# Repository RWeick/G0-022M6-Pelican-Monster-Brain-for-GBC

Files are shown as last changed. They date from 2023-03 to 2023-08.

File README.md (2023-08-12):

# G0-022M6-Pelican-Monster-Brain-for-GBC
The schematics, PCB, and flash dumps of three versions of the GBC Pelican Monster Brain.

Version 1.1 is for Pokemon Red and Blue, and comes in a case with a blue BrainBoy sticker/logo.
Version 2.0 is for Pokemon Gold and Silver, and comes in a case with a gold BrainBoy sticker/logo.
Version 3.6 is for every Gameboy Pokemon edition, and comes in a case with a purple Monster Brain sticker/logo.

All components labeled "Unknown" in the schematic were not present on the commercial PCB. This PCB is used for both the Monster Brain and the Codebreaker, and the missing components are present when this board is used in a Codebreaker.

The CPLD is the same between all devices.

The Colorizer button PCB wires solder to the inner two pads of the 4 at the rear top edge of the PCB.

Jumper configuration for normal operation: 

- J1: Pads 2 and 3 are shorted.
- J2: Open.
- J3: Shorted.
- J4: Shorted.

The CPLD functions I've been able to deduce are as follows:

A read must be performed at address 0x100 in order to enable address banking in the CPLD.

The write address to change banks is 0xA000.

The full rom is available from 0x2000 to 0x3FFF by switching either 32 or 64 banks depending on the device. The blue label Brainboy has 64 banks, and the rest of the devices use 32 banks due to smaller eeproms. The maximum known EEPROM size included with an off the shelf device is 512 KB.

PCB Thickness: 0.8 mm

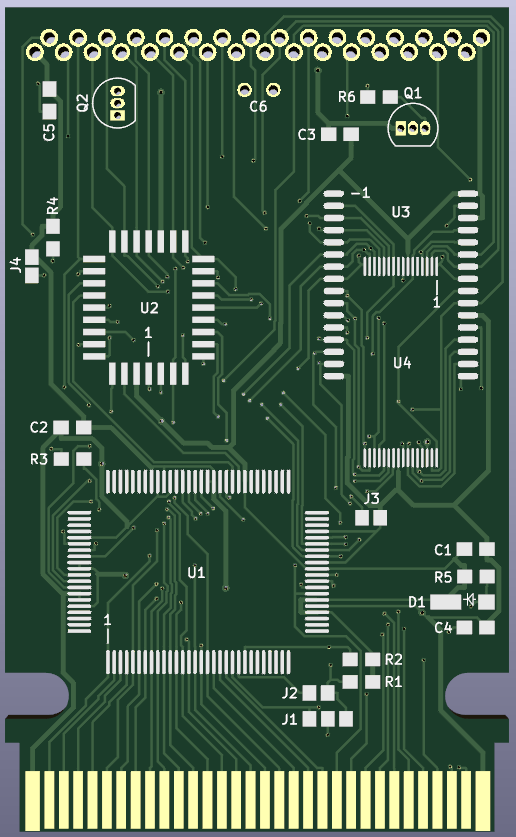
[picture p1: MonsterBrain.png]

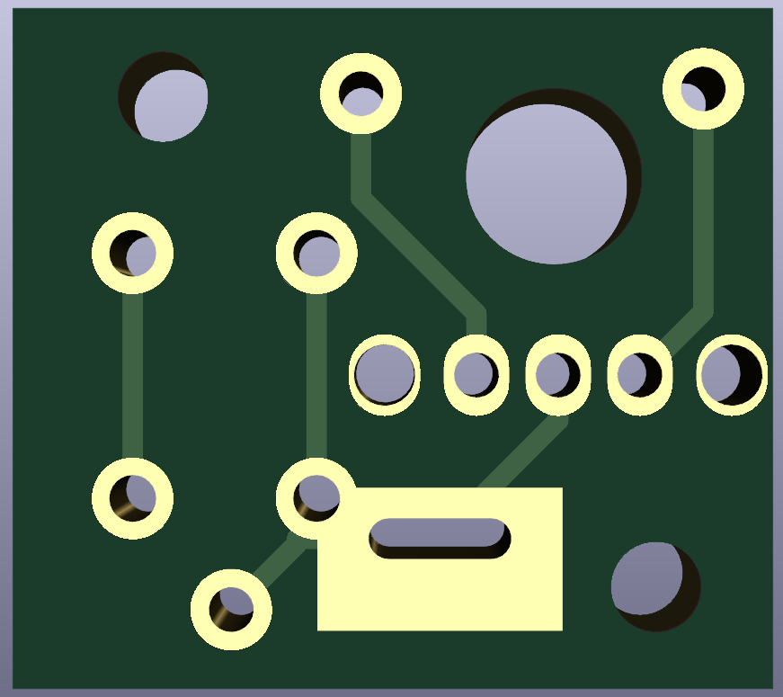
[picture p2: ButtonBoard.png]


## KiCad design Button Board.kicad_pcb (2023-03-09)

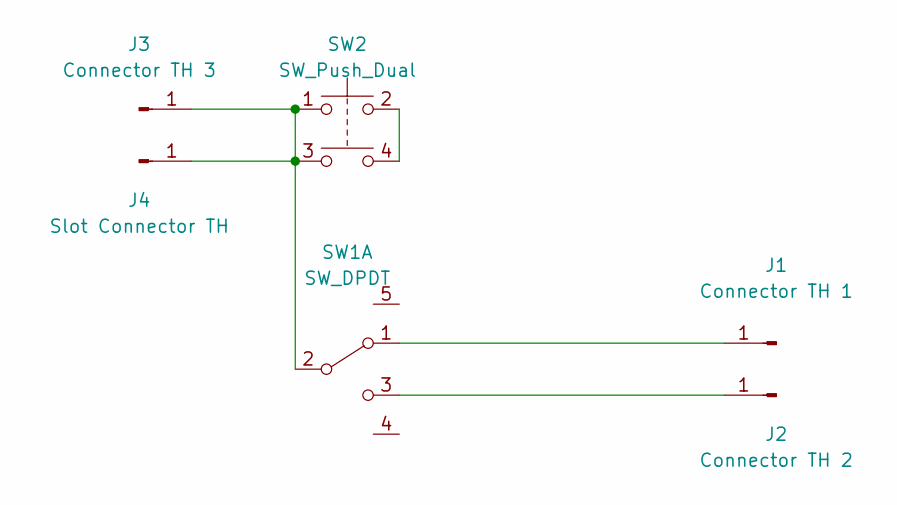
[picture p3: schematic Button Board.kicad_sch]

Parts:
J1: Connector TH 1; Connector Hole
J2: Connector TH 2; Connector Hole
J3: Connector TH 3; Connector Hole
J4: Slot Connector TH; Square Slot
SW1: SW_DPDT; Sliding Switch
SW2: SW_Push_Dual; Push Button

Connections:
unnamed: J1.1, SW1.1 (A)
unnamed: J2.1, SW1.3 (C)
unnamed: J3.1, J4.1, SW1.2 (B), SW2.1, SW2.3
unnamed: SW2.2, SW2.4

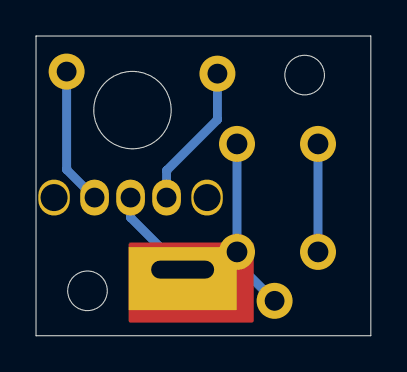
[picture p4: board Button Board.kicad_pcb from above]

Board: 2 copper layers, 18.6 x 16.6 mm, 9 parts (0 on the bottom side), 4 nets.

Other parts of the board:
H1, H3: MountingHole_2.2mm_M2
H2: MountingHole_4.3mm_M4

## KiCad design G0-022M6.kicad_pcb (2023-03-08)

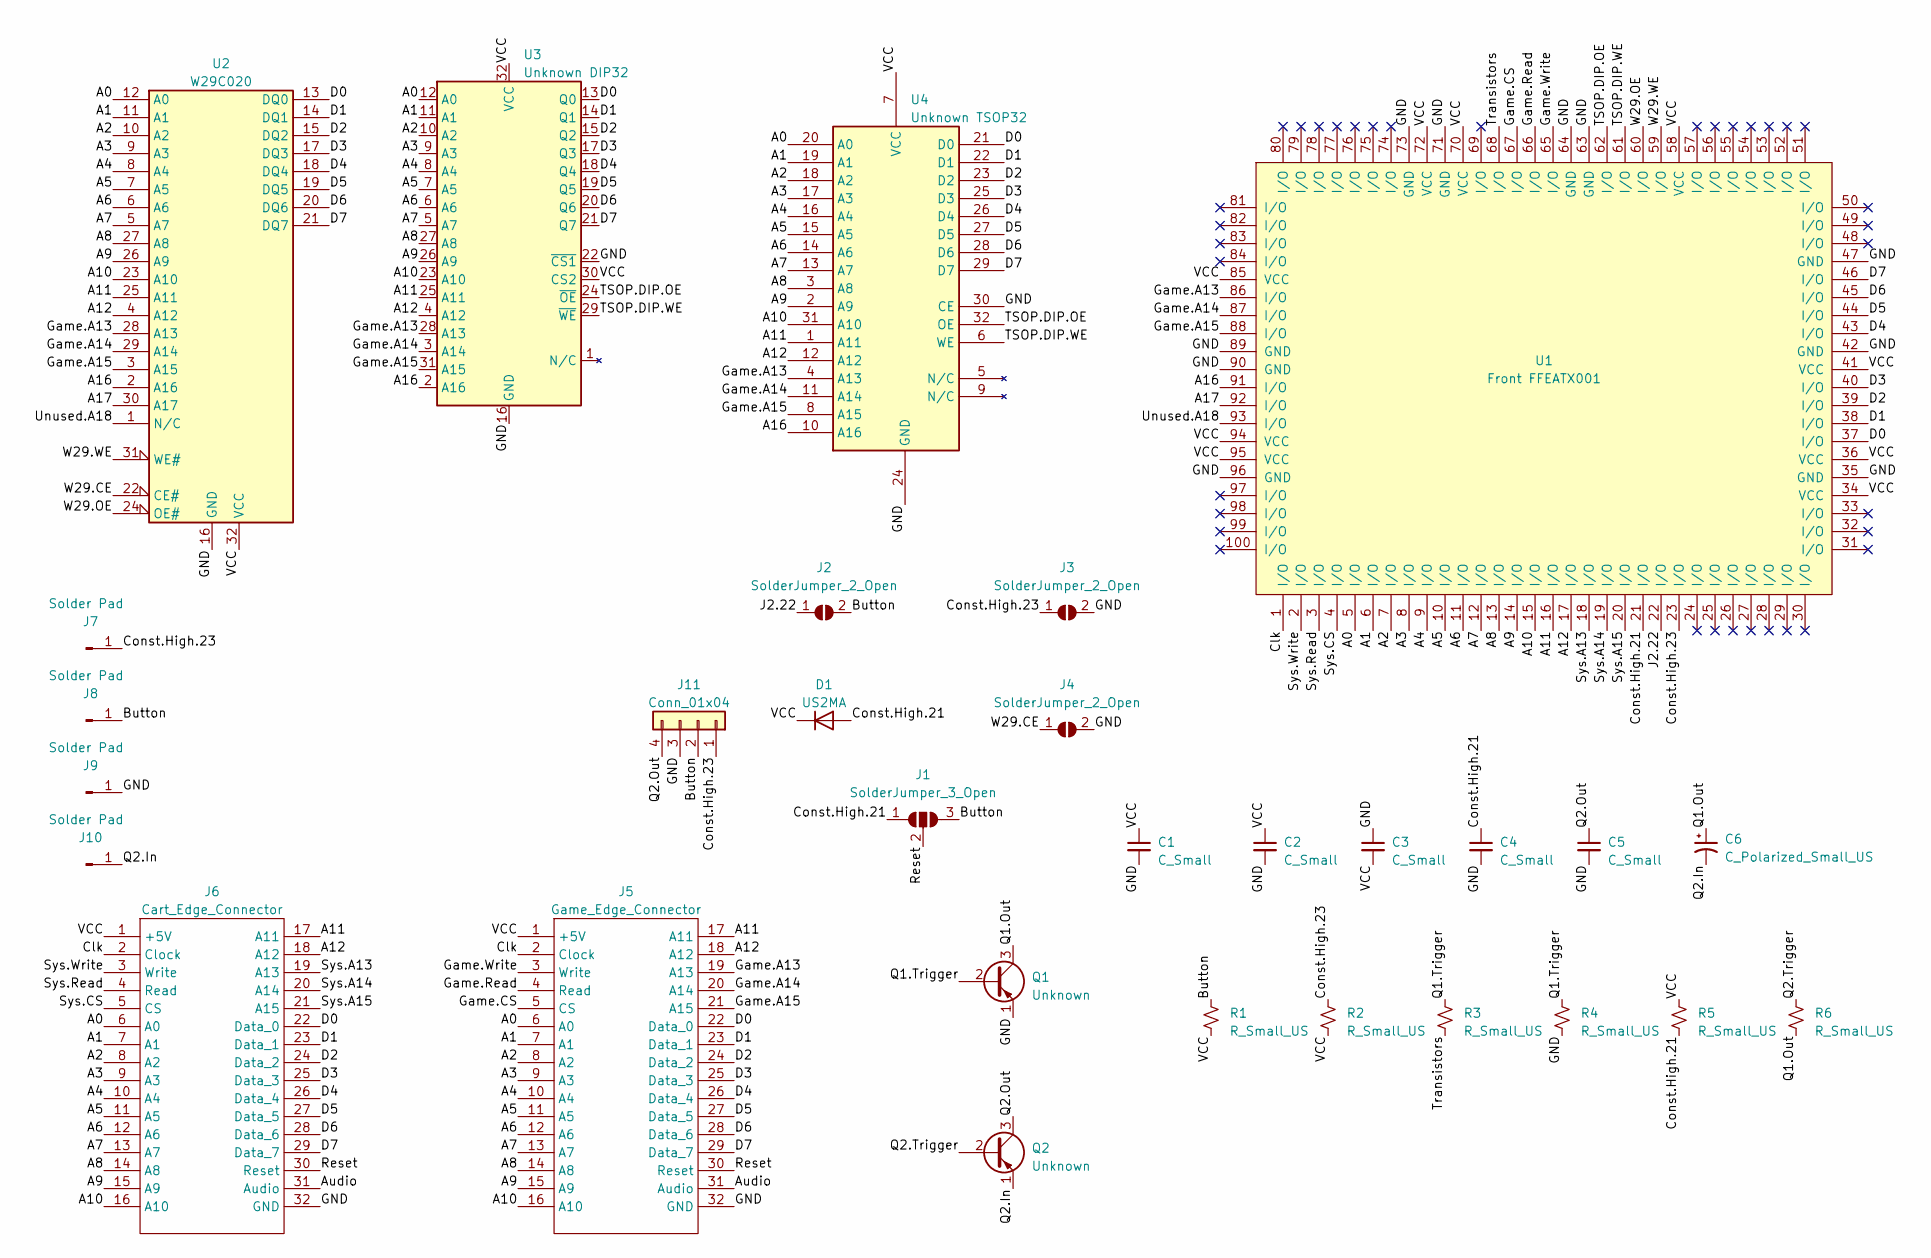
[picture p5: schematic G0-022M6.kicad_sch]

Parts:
C1, C2, C3, C4, C5: C_Small; SMD Cap
C6: C_Polarized_Small_US; TH Cap
D1: US2MA; Diode
J1: SolderJumper_3_Open; 3 Pad Jumper
J2, J3, J4: SolderJumper_2_Open; 2 Pad Jumper
J5: Game_Edge_Connector; Cartridge Slot, GBC
J6: Cart_Edge_Connector; ACTUAL GAMEBOY EDGE CONNECTOR
J7, J8, J9, J10: Solder Pad; Rear Circle Pad
J11: Conn_01x04; Rear Edge
Q1, Q2: Unknown; TO-92_Inline
R1, R2, R3, R4, R5, R6: R_Small_US; SMD Res
U1: Front FFEATX001; FFEATX001
U2: W29C020
U3: Unknown DIP32; Unknown Dip
U4: Unknown TSOP32; Unknown TSOP

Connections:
/A0: J5.6 (A0), J6.6 (A0), U1.5 (I/O), U2.12 (A0), U3.12 (A0), U4.20 (A0)
/A1: J5.7 (A1), J6.7 (A1), U1.6 (I/O), U2.11 (A1), U3.11 (A1), U4.19 (A1)
/A2: J5.8 (A2), J6.8 (A2), U1.7 (I/O), U2.10 (A2), U3.10 (A2), U4.18 (A2)
/A3: J5.9 (A3), J6.9 (A3), U1.8 (I/O), U2.9 (A3), U3.9 (A3), U4.17 (A3)
/A4: J5.10 (A4), J6.10 (A4), U1.9 (I/O), U2.8 (A4), U3.8 (A4), U4.16 (A4)
/A5: J5.11 (A5), J6.11 (A5), U1.10 (I/O), U2.7 (A5), U3.7 (A5), U4.15 (A5)
/A6: J5.12 (A6), J6.12 (A6), U1.11 (I/O), U2.6 (A6), U3.6 (A6), U4.14 (A6)
/A7: J5.13 (A7), J6.13 (A7), U1.12 (I/O), U2.5 (A7), U3.5 (A7), U4.13 (A7)
/A8: J5.14 (A8), J6.14 (A8), U1.13 (I/O), U2.27 (A8), U3.27 (A8), U4.3 (A8)
/A9: J5.15 (A9), J6.15 (A9), U1.14 (I/O), U2.26 (A9), U3.26 (A9), U4.2 (A9)
/A10: J5.16 (A10), J6.16 (A10), U1.15 (I/O), U2.23 (A10), U3.23 (A10), U4.31 (A10)
/A11: J5.17 (A11), J6.17 (A11), U1.16 (I/O), U2.25 (A11), U3.25 (A11), U4.1 (A11)
/A12: J5.18 (A12), J6.18 (A12), U1.17 (I/O), U2.4 (A12), U3.4 (A12), U4.12 (A12)
/A16: U1.91 (I/O), U2.2 (A16), U3.2 (A16), U4.10 (A16)
/A17: U1.92 (I/O), U2.30 (A17)
/Audio: J5.31 (Audio), J6.31 (Audio)
/Button: J1.3 (B), J2.2 (B), J8.1, J11.2, R1.1
/Clk: J5.2 (Clock), J6.2 (Clock), U1.1 (I/O)
/Const.High.21: C4.1, D1.2 (A), J1.1 (A), R5.2, U1.21 (I/O)
/Const.High.23: J3.1 (A), J7.1, J11.1, R2.1, U1.23 (I/O)
/D0: J5.22 (Data_0), J6.22 (Data_0), U1.37 (I/O), U2.13 (DQ0), U3.13 (Q0), U4.21 (D0)
/D1: J5.23 (Data_1), J6.23 (Data_1), U1.38 (I/O), U2.14 (DQ1), U3.14 (Q1), U4.22 (D1)
/D2: J5.24 (Data_2), J6.24 (Data_2), U1.39 (I/O), U2.15 (DQ2), U3.15 (Q2), U4.23 (D2)
/D3: J5.25 (Data_3), J6.25 (Data_3), U1.40 (I/O), U2.17 (DQ3), U3.17 (Q3), U4.25 (D3)
/D4: J5.26 (Data_4), J6.26 (Data_4), U1.43 (I/O), U2.18 (DQ4), U3.18 (Q4), U4.26 (D4)
/D5: J5.27 (Data_5), J6.27 (Data_5), U1.44 (I/O), U2.19 (DQ5), U3.19 (Q5), U4.27 (D5)
/D6: J5.28 (Data_6), J6.28 (Data_6), U1.45 (I/O), U2.20 (DQ6), U3.20 (Q6), U4.28 (D6)
/D7: J5.29 (Data_7), J6.29 (Data_7), U1.46 (I/O), U2.21 (DQ7), U3.21 (Q7), U4.29 (D7)
/GND: C1.2, C2.2, C3.1, C4.2, C5.2, J3.2 (B), J4.2 (B), J5.32 (GND), J6.32 (GND), J9.1, J11.3, Q1.1 (E), R4.2, U1.35 (GND), U1.42 (GND), U1.47 (GND), U1.63 (GND), U1.64 (GND), U1.71 (GND), U1.73 (GND), U1.89 (GND), U1.90 (GND), U1.96 (GND), U2.16 (GND), U3.16 (GND), U3.22 (~CS1), U4.24 (GND), U4.30 (CE)
/Game.A13: J5.19 (A13), U1.86 (I/O), U2.28 (A13), U3.28 (A13), U4.4 (A13)
/Game.A14: J5.20 (A14), U1.87 (I/O), U2.29 (A14), U3.3 (A14), U4.11 (A14)
/Game.A15: J5.21 (A15), U1.88 (I/O), U2.3 (A15), U3.31 (A15), U4.8 (A15)
/Game.CS: J5.5 (CS), U1.67 (I/O)
/Game.Read: J5.4 (Read), U1.66 (I/O)
/Game.Write: J5.3 (Write), U1.65 (I/O)
/J2.22: J2.1 (A), U1.22 (I/O)
/Q1.Out: C6.1, Q1.3 (C), R6.2
/Q1.Trigger: Q1.2 (B), R3.1, R4.1
/Q2.In: C6.2, J10.1, Q2.1 (E)
/Q2.Out: C5.1, J11.4, Q2.3 (C)
/Q2.Trigger: Q2.2 (B), R6.1
/Reset: J1.2 (C), J5.30 (Reset), J6.30 (Reset)
/Sys.A13: J6.19 (A13), U1.18 (I/O)
/Sys.A14: J6.20 (A14), U1.19 (I/O)
/Sys.A15: J6.21 (A15), U1.20 (I/O)
/Sys.CS: J6.5 (CS), U1.4 (I/O)
/Sys.Read: J6.4 (Read), U1.3 (I/O)
/Sys.Write: J6.3 (Write), U1.2 (I/O)
/TSOP.DIP.OE: U1.62 (I/O), U3.24 (~OE), U4.32 (OE)
/TSOP.DIP.WE: U1.61 (I/O), U3.29 (~WE), U4.6 (WE)
/Transistors: R3.2, U1.68 (I/O)
/Unused.A18: U1.93 (I/O), U2.1 (N/C)
/VCC: C1.1, C2.1, C3.2, D1.1 (K), J5.1 (+5V), J6.1 (+5V), R1.2, R2.2, R5.1, U1.34 (VCC), U1.36 (VCC), U1.41 (VCC), U1.58 (VCC), U1.70 (VCC), U1.72 (VCC), U1.85 (VCC), U1.94 (VCC), U1.95 (VCC), U2.32 (VCC), U3.30 (CS2), U3.32 (VCC), U4.7 (VCC)
/W29.CE: J4.1 (A), U2.22 (CE#)
/W29.OE: U1.60 (I/O), U2.24 (OE#)
/W29.WE: U1.59 (I/O), U2.31 (WE#)

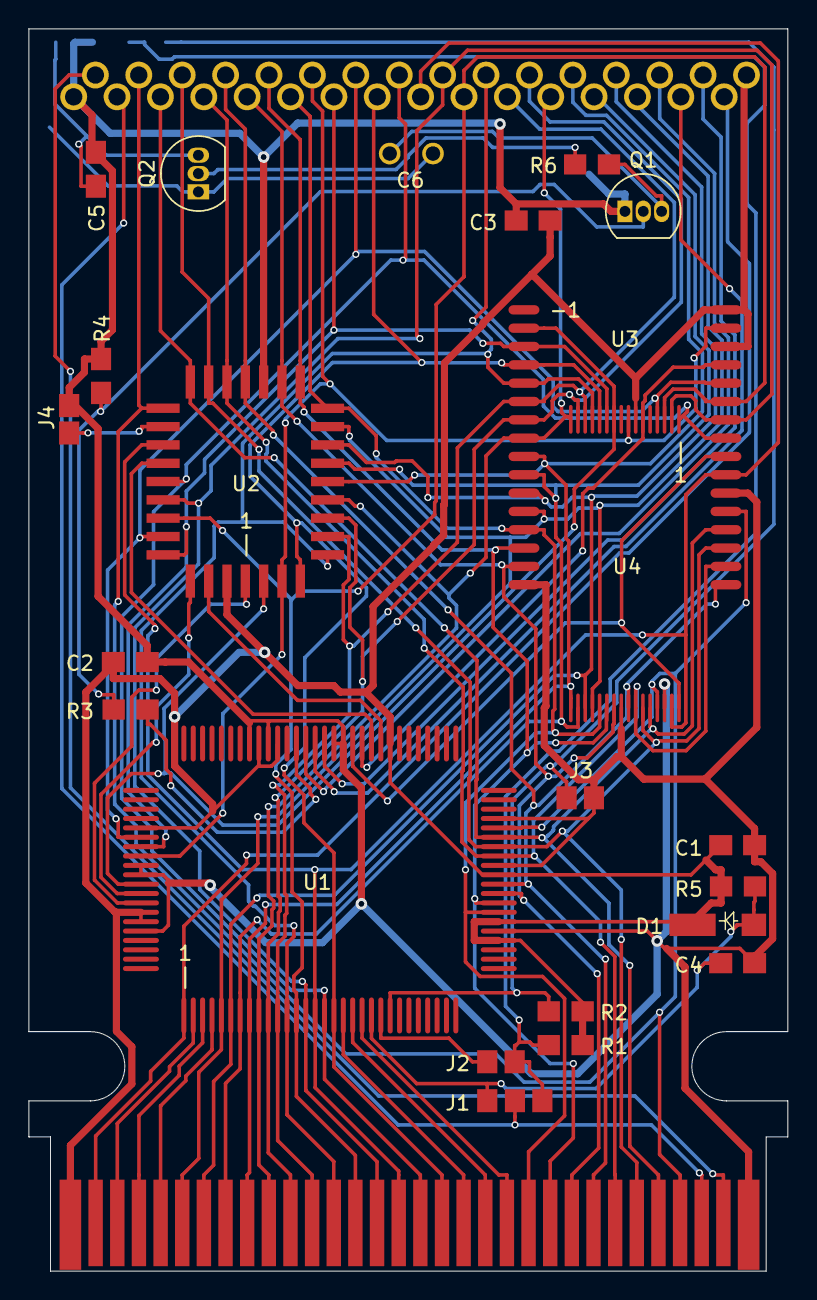
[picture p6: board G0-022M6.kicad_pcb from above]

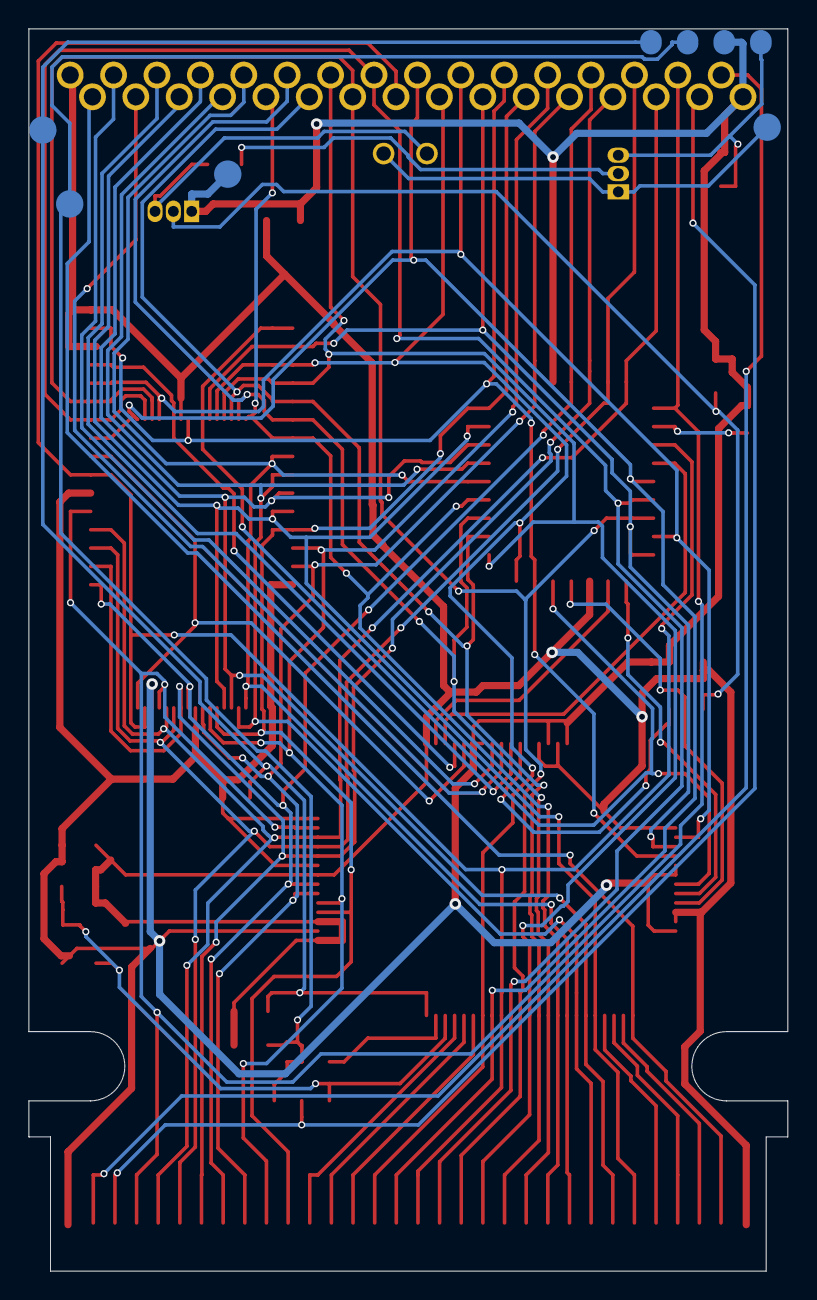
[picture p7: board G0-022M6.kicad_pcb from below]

Board: 2 copper layers, 52.6 x 86.1 mm, 30 parts (5 on the bottom side), 56 nets.
